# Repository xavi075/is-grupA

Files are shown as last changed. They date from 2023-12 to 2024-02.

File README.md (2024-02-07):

# Sensor Center: control and automate crop irrigation

## General description
Over the past few months, Ferran, Arnau, and I have been collaborating on a project to control and automate crop irrigation. The device is autonomous and includes a battery that is recharged with solar energy. 

The project involves designing and 3D printing the encapsulation, developing the device firmware, creating software for a master device that connects the sensors to a cloud database through an API, and designing an intuitive graphical interface that is easy to use and fully portable for any electronic device. This allows the user to control their irrigation system from anywhere. 

The firmware was developed using C++, while the master software and database API were implemented in Python. MySQL was used as the database management system. The web application was developed with React and Typescript and its service was launched into production using Docker on a server.

> [!IMPORTANT]
> Some parts of the firmware are adapted to our hardware needings.

## Web Board
Web-board directory includes the application web project. It is responsive and has been designed based on the requirements of our university project.

> [!WARNING]
> All the packages that must be installed are registered in the package log and must be installed using `npm install` command

In order to run the web app locally, just use `npm start`. Also, currently the requests are pointing to the database. In case of running the database locally, it is strictly necessary to change the Endpoint in the `api.ts` file.

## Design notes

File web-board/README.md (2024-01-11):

# Sensor Center
> [!TIP]
> This is a tip

In order to run this web server, NodeJs and Npm are needed for the building.

Install NodeJs with the following command:

Install Npm with the following command:

Also it is needed to download all the required packages by React:

`npm install`

The last step is building the React project. For a local run:

`npm start`

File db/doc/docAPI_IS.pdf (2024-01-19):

# Documentació API Grup A

### Ferran Casanovas i Arnau Parcerisa

### 18 de gener de 2024

## Índex

1 Introducció | 1
2 Formats de les peticions | 2
3 Peticions POST | 2
4 Peticions GET | 10

## 1 Introducció

En aquest document s’hi pot trobar tota la documentació de la API creada pel grup A, format per l’Arnau Parcerisa, el Xavier Massana i el Ferran Casanovas.

1

EPSEM - Sistemes TIC - 2023/24 | Integració de Sistemes

Aquesta API permet, mitjançant mètodes GET i POST, consultar i inserir dades a la base de dades MySQL dissenyada. Per a la programació d’aquesta API s’ha utilitzat Python3 i Flask.

## 2 Formats de les peticions

En cadascuna de les peticions, s’especifica com ha de ser el format i quines dades contindrà la resposta. En cas de que la petició sigui correcta i no hi hagin errors durant l’execució, el codi de resposta serà 200 i el seu format serà diferent en cada petició, donat que en cadascuna es voldran obtenir dades diferents. No obstant, sempre s’indicarà que no hi han hagut errors retornant una petició amb el format següent:

{
{
"success" = True,
}

En cas que la petició sigui incorrecta, ja sigui perquè aquesta és sintàcticament incorrecta, perquè no s’especifiquen les dades necessàries o perquè el client no està autoritzat per accedir i/o modificar el recurs, el codi de resposta serà 400. Si es produeix algun error durant l’execució el codi de resposta serà 500. En ambdos casos, el format de la resposta serà el següent:

{
"success" = False,
"error" = "descripció del error" }

## 3 Peticions POST

A continuació es descriuen les funcionalitats de totes les peticions de la API que utilitzen el mètode POST, incloent una breu descripció, característiques de seguretat (si n’hi han), el format de la petició i el format de la resposta per a cada petició. Cal destacar que en tots els casos s’espera que en el cos de la petició s’hi inclogui un objecte json.

### 3.1 /assignaDispositiuUsuari

Endpoint de Flask per assignar un dispositiu a un usuari. Només permet assignar-lo si el dispositiu està desassignat, és a dir, que no està assignat a cap altra usuari.

2

### 3.1.1 Format de la petició

{
"idDispositiu": (int),
"idUsuari": (int),
"nomDispositiu": (str)
}

En aquest cas, es poden ocultar camps del json. Els camps del json idDispositiu, idUsuari i nomDispositiu son OBLIGATORIS.

### 3.1.2 Format de la resposta

{
"success" = True
"dades":
{
"idHardcode": (str)
}
}

### 3.2 /desassignaDispositiu

Endpoint de Flask per desassignar un dispositiu a un usuari. Només es pot desassignar un dispositiu si aquest està assignat a un usuari. A més, s’esborren totes les dades del dispositiu de les taules de dades corresponents a les dades de humitat i temperatura (dadesDispositius) i a la de canvis d’estat de reg (canvisReg).

### 3.2.1 Format de la petició

{
"idDispositiu": (int),
"idUsuari": (int)
}

Els camps de la petició idDispositiu i idUsuari són obligatoris.

### 3.2.2 Format de la resposta

{
"success" = True
}

### 3.3 /inserirDada

Endpoint de Flask per inserir dades a la taula dadesDispositius.

3

### 3.3.1 Format de la petició

{
"idHardcode": (str),
"dadaHum": (decimal),
"dadaTemp": (decimal),
}

En aquest cas, es poden ocultar camps del del json. No es pot inserir dades sense que no estigui assignat a cap usuari. Tots els camps del json són OBLIGATORIS.

### 3.3.2 Format de la resposta

{
"success" = True
}

### 3.4 /inserirDispositiu

Endpoint de Flask per inserir dades a la taula dispositius. Permet inserir un dispositiu no assignat a cap usuari. El fet d’inserir un dispositiu no assignat es fa per tal de facilitar la feina del front-end per assignar un nou dispositiu a un usuari. Tot i així, si que és obligatori afegir-li un id que el permeti identificar amb el hardware, anomenat idHardcode.

### 3.4.1 Format de la petició

{
"idHardcode": (str),
"idUsuariPropietari": (int) / None, "nomDispositiu": (str) / None "llindarMinimReg": (decimal) / None, "llindarMaximReg": (decimal) / None }

En aquest cas, es poden ocultar camps del del json. Si es vol inserir un dispositiu que no estigui assignat a cap usuari, s’ha enviar un json que només contingui el id del hardware. Tots els camps del json són OPCIONALS en excepció del idHardcode que és OBLIGATORI.

### 3.4.2 Format de la resposta

Quan el dispositiu s’insereix correctament, s’especifica el id que se li ha assignat al dispositiu inserit.

4

{
"success": True,
"idDispositiu": (int),
"idHardcode": (str)
}

### 3.5 /inserirEstatReg

Endpoint de Flask per inserir dades a la taula canvisReg. Aquest només insereix és els canvis, és a dir només insereix la dada si l’últim estat del reg del dispositiu és diferent.

### 3.5.1 Format de la petició

{
"idHardcode": (int),
"estatReg": (bool)
}

Si el cos de la petició no conté un json amb els camps idHardcode i estatReg, les dades no s’inseriran. Tots els camps del json són OBLIGATORIS.

### 3.5.2 Format de la resposta

Si tot funciona correctament, s’especifica si la dada s’ha inserit o no depenent de si aquesta és diferent o no a l’últim estat del reg del dispositiu guardat.

{
"success" = True,
"dadaInserida": (bool)
}

### 3.6 /inserirUsuari

Endpoint de Flask per inserir dades a la taula usuaris. Al inserir un usuari, s’insereix a la base de dades la data utf de creació de l’usuari, aquesta data no s’ha d’especificar en la petició.

### 3.6.1 Seguretat

S’ha d’enviar la contrasenya sense aplicar cap funció de hash, ja que la mateixa petició és la que s’encarrega d’aplicar-lo.

5

### 3.6.2 Format de la petició

{
"email": (str),
"nomUsuari": (str),
"contrasenya": (str)
}

Si el cos de la petició no conté un json amb els camps email, nomUsuari i contrasenya, les dades de l’usuari no s’inseriran. Tots els camps del json són OBLIGATO-RIS.

### 3.6.3 Format de la resposta

Quan l’usuari s’insereix correctament, s’especifica el id que se li ha assignat a l’usuari insertat.

{
"success": True,
"idUsuariInsertat": (int)
}

### 3.7 /modificaContrasenya

Endpoint de Flask per modificar la contrasenya d’un usuari. Per tal de modificarla és necessari indicar la contrasenya actual i que aquesta sigui correcta.

### 3.7.1 Seguretat

S’ha d’enviar tant la contrasenya actual com la nova contrasenya sense aplicar cap funció de hash, donat que la mateixa petició s’encarrega de:

- Aplicar la funció de hash a la contrasenya actual indicada i comprovar que coincideixi amb la guardada a la base de dades.
- Guardar la nova contrasenya amb la funció de hash aplicada.

### 3.7.2 Format de la petició

{
"idUsuari": (int),
"contrasenya": (str),
"novaContrasenya": (str)
}

Si el cos de la petició no conté un json amb els camps idUsuari, contrasenya i novaContrasenya, la contrasenya no es modificarà. Tots els camps del json són OBLIGATORIS.

6

### 3.7.3 Format de la resposta

Indica si s’ha modificat la contrasenya correctament.

{
"success" = True
}

### 3.8 /modificaLlindars

Endpoint de Flask per modificar els llindars de reg d’un dispositiu. S’emmagatzemen els llindars modificats per si es demana en la petició GET /obtenirModificacionsLlindars. Si ja hi ha algun canvi de llindar entrat, se’l substitueix.

### 3.8.1 Format de la petició

{
"idDispositiu": (int),
"llindarMinimReg": (decimal), "llindarMaximReg": (decimal) }

Si el cos de la petició no conté un json amb els camps idDispositiu, llindarMinimReg i llindarMaximReg, la petició donarà a un error amb codi 400. Els camps del json idDispositiu, llindarMinimReg i llindarMaximReg són OBLIGATORIS.

### 3.8.2 Format de la resposta

Indica si s’han modificat els llindars correctament.

{
"success" = True
}

### 3.9 /verificaLogIn

Endpoint de Flask per obtenir si les credencials de log in es corresponen a les credencials de la base de dades. Si troba les credencials, retorna el identificador de l’usuari per facilitar el logIn.

### 3.9.1 Seguretat

S’ha d’enviar la contrasenya sense aplicar cap funció de hash, ja que la mateixa petició s’encarrega d’aplicar-la i comprovar que coincideixi amb la guardada a la base de dades.

7

### 3.9.2 Format de la petició

{
"emailUsuari": (str),
"contrasenya": (str)
}

Si el cos de la petició no conté un json amb els camps emailUsuari i contrasenya, la petició donarà a un error amb codi 400. Tots els camps del json són OBLI-GATORIS.

### 3.9.3 Format de la resposta

Indica si s’ha trobat una coincidència de les credencials a la base de dades o no i retorna l’identificador de l’usuari per facilitar el LogIn. També retorna si l’usuari està verificat o no.

{
"success" = True,
"credencialsTrobades": (bool), "idUsuari": (int) / None,
"usuariVerificat": (bool)
}

### 3.10 /verificaUsuari

Endpoint de Flask per verificar el codi de verificació d’un usuari.

### 3.10.1 Format de la petició

{
"idUsuari": (int),
"codi": (str)
}

Si el cos de la petició no conté un json amb els camps idUsuari i codi, la petició donarà a un error amb codi 400. Tots els camps del json són OBLIGATORIS.

### 3.10.2 Format de la resposta

Indica si s’ha trobat una coincidència del codi de verificació a la base de dades o no i un boolea que indica si el codi introduit i el de la base de dades eren els mateixos i, per tant, l’usuari s’ha verificat (True) o, en cas contrari, els codis no coincideixen i, per tant, l’usuari no s’ha verificat (False).

8

{
"success" = True,
"usuariVerificat": (bool)
}

9

## 4 Peticions GET

A continuació es decriuen les funcionalitats de totes les peticions de la API que utilitzen el mètode GET, incloent una breu descripció, descripció dels paràmetres de la petició, el format de la resposta i exemples per a cada petició. Cal destacar que el format de resposta de totes les peticions GET serà el següent:

{
"success" = True,
"dades":
[
]
}

On dintre de la llista dades s’hi emmagatzemaran les dades que es volen consultar, generalment dintre de diccionaris on cada diccionari es correspon a una fila de la base de dades. Les dades que es retornaran en cada petició i el seu format s’especificarà en la descripció de cadascuna d’elles.

### 4.1 /obtenirCanvisReg

Endpoint de Flask per obtenir dades de la taula canvisReg, on estan emmagatzemats els canvis en l’estat del reg.

### 4.1.1 Paràmetres de la petició

- idUsuari (opcional): identificador del usuari del qual es vol obtenir els canvis en l’estat del reg dels seus dispositius assignats.
- idDispositiu (opcional): identificador del dispositiu del qual es volen obtenir els canvis en l’estat del reg.
- dataInici (opcional): data a partir de la qual es volen obtenir els canvis en l’estat del reg.
- dataFi (opcional): data fins a la qual es volen obtenir els canvis en l’estat del reg.

Si no s’especifiquen cap dels paràmetres, s’obtindran totes les dades emmagatzemades en la taula canvisReg. Si s’especifiquen els paràmetres idUsuari i idDispositiu, es filtrarà per l’identificador del dispositiu. Els paràmetres dataInici i/o dataFi han d’anar acompanyats del paràmetre idUsuari o idDispositiu, en cas contrari s’obtindran totes les dades sense filtrar per data. Es pot especificar el paràmetre dataInici sense especificar dataFi, però si s’especifica dataFi sense especificar dataInici aquest s’ignorarà.

10

### 4.1.2 Format de la resposta

{
"success" = True,
"dades":
[
{
"idDispositiu": (int),
"dataHora": (datetime),
"estatReg": (bool)
},
]
}

### 4.1.3 Exemples de peticions

- Obtenir totes les dades:

GET /obtenirCanvisReg

- Obtenir totes les dades dels dispositius assignats a un usuari en concret:

GET /obtenirCanvisReg?idUsuari=1

- Obtenir totes les dades d’un dispositiu:

GET /obtenirCanvisReg?idDispositiu=1

- Obtenir totes les dades dels dispositius assignats a un usuari indicant data
inici i data fi:

GET /obtenirCanvisReg?idUsuari=1&dataInici=2023-11-16 00:01:00 &dataFi=31-12-2023 23:59:00

- Obtenir totes les dades d’un dispositiu indicant data inici i data fi:

GET /obtenirCanvisReg?idDispositiu=1&dataInici=01-01-2023 00:01:00 &dataFi=31-12-2023 23:59:00

### 4.2 /obtenirDadesDispositius

Endpoint de Flask per obtenir dades de la taula dadesDispositius, on estan emmagatzemats els valors de temperatura i d’humitat.

### 4.2.1 Paràmetres de la petició

- idUsuari (opcional): identificador del usuari del qual es volen obtenir les dades dels seus dispositius assignats.

11

- idDispositiu (opcional): identificador del dispositiu del qual es volen obtenir les dades.
- dataInici (opcional): data a partir de la qual es volen obtenir les dades.
- dataFi (opcional): data fins a la qual es volen obtenir les dades.

Si no s’especifiquen cap dels paràmetres, s’obtindran totes les dades emmagatzemades en la taula dadesDispositius. Si s’especifiquen els paràmetres idUsuari i idDispositiu, es filtrarà per l’identificador del dispositiu. Els paràmetres dataInici i/o dataFi han d’anar acompanyats del paràmetre idUsuari o idDispositiu, en cas contrari s’obtindran totes les dades sense filtrar per data. Es pot especificar el paràmetre dataInici sense especificar dataFi, però si s’especifica dataFi sense especificar dataInici aquest s’ignorarà.

### 4.2.2 Format de la resposta

{
"success" = True,
"dades":
[
{
"idDispositiu": (int),
"dataHora": (datetime),
dadaHum: (decimal),
dataTemp: (decimal
},
]
}

### 4.2.3 Exemples de peticions

- Obtenir totes les dades:

GET /obtenirDadesDispositius

- Obtenir totes les dades dels dispositius assignats a un usuari en concret:

GET /obtenirDadesDispositius?idUsuari=1

- Obtenir totes les dades d’un dispositiu:

GET /obtenirDadesDispositius?idDispositiu=1

- Obtenir totes les dades dels dispositius assignats a un usuari indicant data inici i data fi:

GET /obtenirDadesDispositius?idUsuari=1&dataInici=2023-11-16 00:01:00 &dataFi=31-12-2023 23:59:00

12

- Obtenir totes les dades d’un dispositiu indicant data inici i data fi:

GET /obtenirDadesDispositius?idDispositiu=1&dataInici=01-01-2023 00:01:00 &dataFi=31-12-2023 23:59:00

### 4.3 /obtenirDispositius

Endpoint de Flask per obtenir dades de la taula dispositius.

### 4.3.1 Paràmetres de la petició

- idUsuari (opcional): id de l’usuari del qual es volen obtenir les dades dels seus dispositius assignats.
- nomDispositiu (opcional): nom del dispositiu del qual es volen obtenir les dades. Sempre ha d’anar acompanyat d’un idUsuari, ja que diferents usuaris poden tenir dispositius amb el mateix nom.
- idDispositiu (opcional): id del dispositiu del qual es poden obtenir les dades.

Si no s’especifica cap dels paràmetres, s’obtindran les dades de tots els dispositius. Si s’especifica el paràmetre idDispositiu, es filtrarà per aquest encara que s’especifiquin més paràmetres.

### 4.3.2 Format de la resposta

{
"success" = True,
"dades":
[
{
"id": (int),
"idHardcode": (str),
"idUsuariPropietari": (int), "nomDispositiu": (str),
"llindarMinimReg": (decimal), "llindarMaximReg": (decimal) },
]
}

### 4.3.3 Exemples de peticions

- Obtenir totes les dades:

GET /obtenirDispositius

13

- Obtenir les dades dels dispositius d’un usuari a partir d’un idUsuari:

GET /obtenirDispositius?idUsuari=1

- Obtenir les dades d’un dispositiu en concret a partid del id:

GET /obtenirDispositius?idDispositiu=1

- Obtenir les dades d’un dispositiu en concret a partir del id del usuari i el nom de dispositiu:

GET /obtenirDispositius?idUsuari=1&nomDispositiu=dispo1

### 4.4 /obtenirDispositiusDesassignats

Endpoint de Flask per obtenir els dispositius que no estan assignats a cap usuari, és a dir, que la columna idUsuariPropietari = NULL.

### 4.4.1 Paràmetres de la petició

Aquesta petició no té paràmetres, donat que al realitzar-la s’obtindran tots els dispositius desassignats.

### 4.4.2 Format de la resposta

{
"success" = True,
"dades":
[
{
"idDispositiu": (int),
"idHardcode": (str)
},
]
}

### 4.4.3 Exemples de peticions

- Obtenir tots els dispositius desassignats:

GET /obtenirDispositiusDesassignats

### 4.5 /comprovacioDispositiuInserit

Endpoint de Flask per comprovar si un dispositiu ha sigut inserit a la base de dades i està assignat.

14

### 4.5.1 Paràmetres de la petició

- idHardcode (obligatori): identificador únic del dispositiu.

Si no s’especifica el paràmetre idHardcode, la petició donarà lloc a un error amb codi 400. El paràmetre de la petició és OBLIGATORI.

### 4.5.2 Format de la resposta

{
"success": True,
"dispositiuTrobat": (bool), "assignat": (bool)
}

### 4.5.3 Exemples de peticions

- Comprovar si un dispositiu està inserit a la base de dades:

GET /comprovacioDispositiuInserit?idHardcode=A

### 4.6 /obtenirUsuaris

Endpoint de Flask per obtenir dades de la taula usuaris. Permet obtenir les dades d’un usuari en concret o de tots els usuaris. Cal tenir en compte que mitjançant aquest mètode mai es podran obtenir les contrasenyes dels usuaris, ni tan sols amb la funció hash aplicada.

### 4.6.1 Paràmetres de la petició

- idUsuari (opcional): identificador del usuari del qual es volen obtenir les dades.
- emailUsuari (opcional): correu electrònic del usuari del qual es volen obtenir les dades.

Si no s’especifica cap dels dos paràmetres, s’obtindran les dades de tots els usuaris. Si s’especifiquen els dos paràmetres, es filtrarà per l’identificador de l’usuari.

### 4.6.2 Format de la resposta

{
"success" = True,
"dades":
[
{
"id": (int),

15

"email": (str),
nomUsuari: (str),
dataCreacioUsuari: (datetime) },
]
}

### 4.6.3 Exemples de peticions

- Obtenir les dades de tots els usuaris:

GET /obtenirUsuaris

- Obtenir les dades d’un usuari en concret mitjançant el id:

GET /obtenirUsuaris?idUsuari=1

- Obtenir les dades d’un usuari en concret mitjançant el email:

GET /obtenirUsuaris?emailUsuari=usuari@exemple.com

### 4.7 /obtenirUltimReg

Endpoint de Flask per obtenir les dades del últim reg d’un dispositiu.

### 4.7.1 Paràmetres de la petició

- idDispositiu (obligatori): identificador del dispositiu del qual es volen obtenir les dades de l’últim reg.

Si no s’especifica el paràmetre idDispositiu, la petició donarà lloc a un error amb codi 400. El paràmetre de la petició és OBLIGATORI.

### 4.7.2 Format de la resposta

{
"success" = True,
"dades":
[
{
"dataHoraInici": (datetime) / "", "dataHoraFi": (datetime) / ""
}
]
}

Es poden donar tres opcions, que donen tres respostes diferents:

16

- S’ha començat i s’ha acabat de regar: l’últim reg s’ha finalitzat, pel que la bomba es troba parada. dataHoraInici indica el moment en el qual s’ha començat a regar i dataHoraFi indica el moment en el qual s’ha finalitzat el reg.
- S’ha començat a regar i no s’ha acabat el reg: l’últim reg no s’ha finalitzat, pel que la bomba es troba engegada. dataHoraInci indica el moment en el qual s’ha començat a regar i dataHoraFi és un string buit.
- No s’ha regat mai: no es tenen dades de cap reg del dispositiu. Tant dataHoraInici com dataHoraFi són strings buits.

### 4.7.3 Exemples de peticions

- Obtenir les dades de l’últim reg d’un dispositiu:

GET /obtenirUltimReg?idDispositiu=1

### 4.8 /obtenirUltimRegUsuari

Endpoint de Flask per obtenir les dades del últim reg de tots els dispositiu d’un usuari.

### 4.8.1 Paràmetres de la petició

- idUsuari (obligatori): identificador del usuari del qual es volen obtenir les dades de l’últim reg de tots els seus dispositius.

Si no s’especifica el paràmetre idUsuari, la petició donarà lloc a un error amb codi 400. El paràmetre de la petició és OBLIGATORI.

### 4.8.2 Format de la resposta

{
"dades":
[
{
"idDispositiu": (int) / "", "nomDispositiu": (str) / "", "dataHoraInici": (datetime) / "", "dataHoraFi": (datetime) / "" },
{
"idDispositiu": (int) / "", "nomDispositiu": (str) / "", "dataHoraInici": (datetime) / "", "dataHoraFi": (datetime) / ""

17

}
]
"success": True,
}

Es poden donar tres opcions, que donen tres respostes diferents:

- S’ha començat i s’ha acabat de regar: l’últim reg s’ha finalitzat, pel que la bomba associada al dispositiu es troba parada. dataHoraInici indica el moment en el qual s’ha començat a regar i dataHoraFi indica el moment en el qual s’ha finalitzat el reg. idDispositiu indica al dispositiu on està connectada la bomba i nomDispositiu indica el seu nom donat.
- S’ha començat a regar i no s’ha acabat el reg: l’últim reg no s’ha finalitzat, pel que la bomba es troba engegada. dataHoraInci indica el moment en el qual s’ha començat a regar i dataHoraFi és un string buit. idDispositiu indica al dispositiu on està connectada la bomba i nomDispositiu indica el seu nom donat.
- No s’ha regat mai: no es tenen dades de cap reg de cap dispositiu de l’usuari. Tant dataHoraInici com dataHoraFi com idDispositiu com nomDispositiu són strings buits.

### 4.8.3 Exemples de peticions

- Obtenir les dades de l’últim reg dels dispositius d’un usuari:

GET /obtenirUltimRegUsuari?idUsuari=1

### 4.9 /obtenirUltimaDadaDispositiu

Endpoint de Flask per obtenir les últimes dades de la taula dadesDispositius. Això inclou obtenir les últimes dades d’un dispositiu en concret o obtenir totes les dades dels dispositius assignats a un usuari.

### 4.9.1 Paràmetres de la petició

- idUsuari (opcional): identificador del usuari del qual es vol obtenir la última dada de cadascun dels dispositius que té assignats.
- idDispositiu (opcional): identificador del dispositiu del qual es vol obtenir la última dada.

Si no s’especifica ni el paràmetre idUsuari ni idDispositiu, la petició donarà lloc a un error amb codi 400. Si s’especifica el paràmetre idDispositiu, es filtrarà per aquest encara que s’especifiqui el paràmetre idUsuari. Els paràmetres de la petició són OPCIONALS, però és OBLIGATORI especificar-ne almenys un.

18

### 4.9.2 Format de la resposta

{
"success" = True,
"dades":
[
{
"idDispositiu": (int),
"nomDispositiu": (str),
"dataHora": (datetime),
"dadaHum": (decimal),
"dadaTemp": (decimal)
},
]
}

### 4.9.3 Exemples de peticions

- Obtenir la última dada d’un dispositiu:

GET /obtenirUltimaDadaDispositiu?idDispositiu=1

- Obtenir la última dada de tots els dispositius assignats a un usuari:

GET /obtenirUltimaDadaDispositiu?idUsuari=1

### 4.10 /obtenirModificacionsLlindars

Endpoint de flask per obtenir la última modificació en els llindars de reg de dispositius. Si es demana d’un dispositiu en concret, com que ja s’ha comunicat el canvi en el llindar, es borra de la llista.

### 4.10.1 Paràmetres de la petició

- idHardcode (opcional): identificador únic del dispositiu del qual es vol obtenir la última modificació en els llindars de reg..

Si no s’especifica el paràmetre, s’obtindran totes les últimes modificacions de llindars de qualsevol dispositiu.

### 4.10.2 Format de la resposta

{
"success" = True,
"dades":
[
{

19

"idHardcode": (str),
"llindarMinimReg": (decimal), "llindarMaximReg": (decimal) },
]
}

Si es retorna una llista buida, vol dir que no existeix cap modificació dels llindars per als paràmetres especificats.

### 4.10.3 Exemples de peticions

- Obtenir les últimes modificacions de llindars de tots els dispositius:

GET /obtenirModificacionsLlindars

- Obtenir la última modificació de llindars d’un dispositiu en concret:

GET /obtenirModificacionsLlindars?idHardcode=A

20

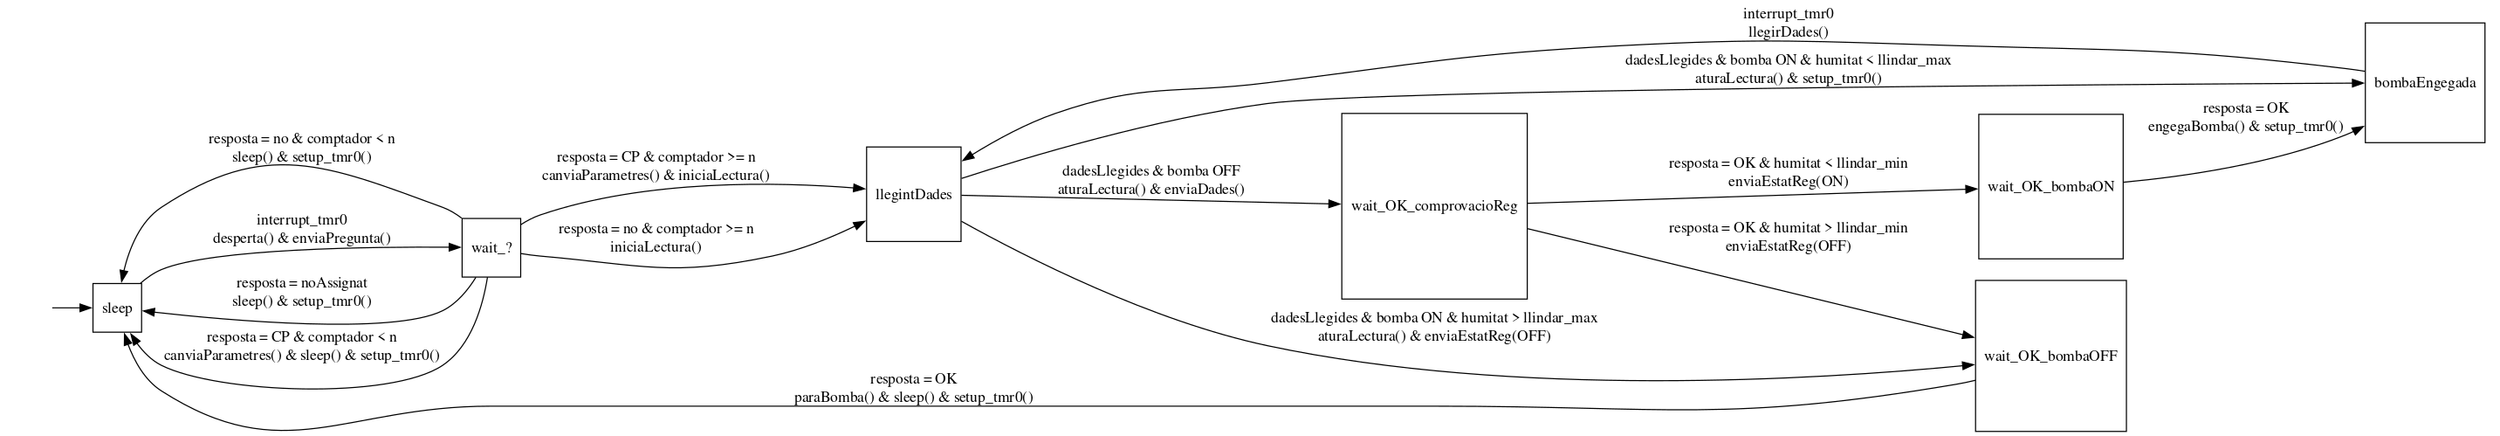
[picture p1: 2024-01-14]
slave/fsm_slave.png

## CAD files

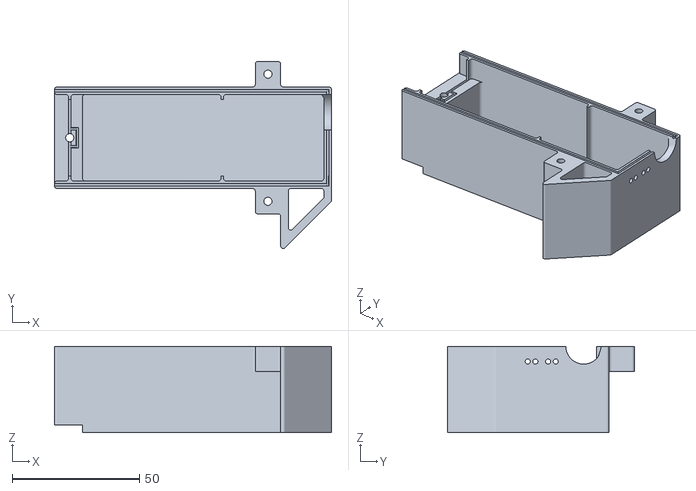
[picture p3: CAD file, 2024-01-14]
arxius3d/encapsulatInf-grupA.stl
109.0 x 73.6 x 34.0

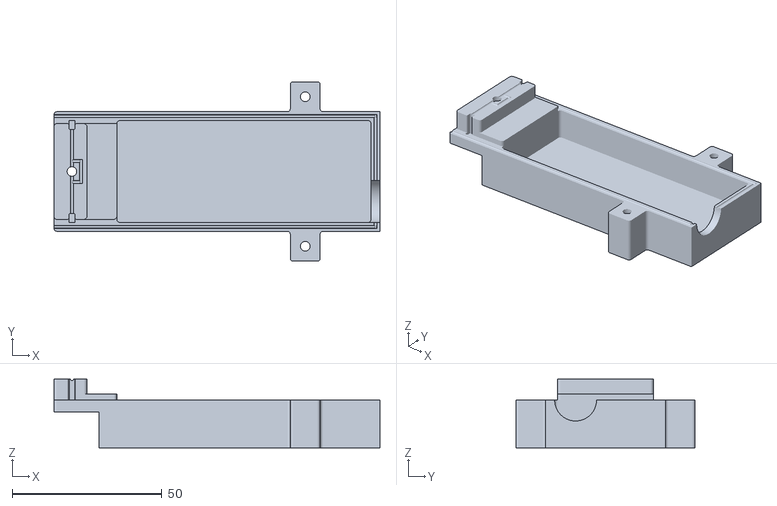
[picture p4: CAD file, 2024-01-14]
arxius3d/encapsulatTapa-grupA.stl
109.0 x 60.0 x 23.0

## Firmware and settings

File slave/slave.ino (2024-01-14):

#include <SPI.h>
#include <LoRa.h>
#include <avr/sleep.h>
#include <avr/power.h>

// per llegir el valor de la temperatura
#include <OneWire.h>
#include <DallasTemperature.h>

#include "adc.h"
#include "modulator.h"
#include "secure.h"
#include "tmr0.h"
#include "tmr2.h"

// Definició dels estats que pot tenir el slave
enum estats_slave {
  sleep,
  wait_resp,
  llegintDades,
  wait_OK_comprovacioReg,
  wait_OK_bombaON,
  wait_OK_bombaOFF,
  bombaEngegada
};
volatile estats_slave estat;

uint8_t localAddress[4] = {0xAA, 0x00, 0x00, 0x00}; // adreça del dispositiu
uint8_t masterAddress[4] = {0x00, 0x00, 0x00, 0x00}; // adreça del dispositiu master
int interval_s = 6000; // interval de temps entre comunicacions amb master

const int num_comunicacions_llegirDades = 6; // variable per indicar cada quantes comunicacions amb el master es llegeixen dades
int num_comunicacions_llegirDades_restants = num_comunicacions_llegirDades - 1; // comunicacions restants per a llegir dades

volatile uint8_t msgId = 0; // comptador dels missatges de sortida
volatile uint8_t lastMsgId; // variable per emmagatzemar l'últim identificador de missatge enviat
String lastOutgoing; // variable per emmagatzemar l'últim missatge
volatile bool lastMsgRespos_flag = true; // flag per indicar si l'últim missatge enviat s'ha respos
const int intervalRepeticioMsg_s = 10; // interval de temps per repetir missatges 
volatile int num_msgRep; // comptador dels cops que s'ha repetit l'últim missatge

// flag per indicar que s'està comunicant amb el master i que no s'ha d'entrar en mode sleep
volatile bool comunicacioMasterFlag = false; 

volatile float llindarMinReg; // llindar a partir del qual es comença a regar
volatile float llindarMaxReg; // llindar a partir del qual es para de regar

const int num_mostresHumitat = 100; // nombre total de mostres d'humitat que es llegiran per cada lectura
volatile int num_mostresHumitat_restants = num_mostresHumitat - 1; // per emmagatzemar el nombre de mostres d'humitat que queden per acabar la lectura
volatile int contenidor_valorHumitat; // variable en la qual es sumaran totes les mostres d'humitat per a després realitzar la mitjana
volatile bool dadesLlegidesFlag; // flag per indicar que s'han llegit totes les mostres d'humitat
float valorHumitat; // variable per emmagatzemar el valor d'humitat llegit

const int valorMaximHumitat = 223; // valor d'humitat amb sensor totalment sec (referència 0% d'humitat)
const int valorMinimHumitat = 45; // valor d'humitat amb sensor totalment mullat (referència 100% d'humitat)

const int pin_temperatura = 14; // pin per on es llegeix la temperatura
OneWire oneWire(pin_temperatura);
DallasTemperature sensors(&oneWire);
float valorTemperatura; // variable per emmagatzemar el valor de temperatura llegit

const int interval_LecturaDades_bombaON_s = 10; // interval de temps per llegir la humitat novament per comprovar si s'ha regat suficient

const int pin_bomba = 6; // pin per activar i desactivar la bomba

// canvia l'estat i el printa
void canviaEstat(estats_slave nouEstat) {
  estat = nouEstat;
  printaEstat();
}

// printa l'estat actual. Únicament serveix per debugar
void printaEstat() {
  switch (estat) {
    case sleep:
      Serial.println("Estat sleep");
      break;
    case wait_resp:
      Serial.println("Estat wait_resp");
      break;
    case llegintDades:
      Serial.println("Estat llegintDades");
      break;
    case wait_OK_comprovacioReg:
      Serial.println("Estat wait_OK_comprovacioReg");
      break;
    case wait_OK_bombaON:
      Serial.println("Estat wait_OK_bombaON");
      break;
    case wait_OK_bombaOFF:
      Serial.println("Estat wait_OK_bombaOFF");
      break;
    case bombaEngegada:
      Serial.println("Estat bombaEngegada");
      break;
    default:
      Serial.println("Estat no reconegut");
      break;
  }
}

// per iniciar la comunicació amb el master. Surt de l'estat sleep i activa el flag
// de comunicació amb el master
void iniciaComunicacioMaster() {
  comunicacioMasterFlag = true;
  canviaEstat(wait_resp);

  sendMessage("preg");

  LoRa.receive();
}

// per finalitzar la comunicació amb el master. Posa el dispositiu amb mode sleep
// i reinicia el timer 0 per tal de que torni a començar la comunicació.
// Canvia al estat sleep i desactiva el flag de comunicació amb el master
void acabaComunicacioMaster() {
  if (num_comunicacions_llegirDades_restants > 0) num_comunicacions_llegirDades_restants--;

  paraBomba();
  comunicacioMasterFlag = false;
  canviaEstat(sleep);
  setup_tmr0(interval_s, iniciaComunicacioMaster);

}

// modifica els llindars de reg del dispositiu
void canviaLlindars(float llindarMin, float llindarMax) {
  Serial.println("Canviant llindars");
  
  llindarMinReg = llindarMin;
  llindarMaxReg = llindarMax;

  
  Serial.print("llindarMin: ");
  Serial.println(llindarMinReg);
  Serial.print("llindarMax: ");
  Serial.println(llindarMaxReg);
}

// s'executa en la interrupció del timer 0 per tornar a calcular el valor de l'humitat després de regar un cert temps.
// Inicia la lectura de dades i modifica l'estat a llegintDades
void bombaEngegada_to_llegintDades() {
  iniciaLectura();
  canviaEstat(llegintDades);
}

// inicia la lectura de dades d'humitat. Això implica engegar el modulator i les interrupcions del timer 2
void iniciaLectura() {
  modulator_set(true);
  tmr2_set(64);
  start_ADC();

  dadesLlegidesFlag = false;
  contenidor_valorHumitat = 0;
  num_mostresHumitat_restants = num_mostresHumitat - 1;
}

// atura la lectura de dades d'humitat. Això implica aturar el modulator i les interrupcions del timer 2
void aturaLectura () {
  modulator_set(false);
  tmr2_set(0);
}

// envia les dades d'humitat i de temperatura especificades en el format que espera el master ("d-H:100T:40")
void enviaDades() {
  String humitat_string = String(valorHumitat);
  String temperatura_string = String(valorTemperatura);

  sendMessage("d-H:" + humitat_string + "T:" + temperatura_string);
}

// envia l'estat del reg
void enviaEstatReg(String estatReg) {
  sendMessage("r-" + estatReg);
}

// engega la bomba
void engegaBomba() {
  digitalWrite(pin_bomba, HIGH);
}

// para la bomba
void paraBomba() {
  digitalWrite(pin_bomba, LOW);
}

// consulta l'estat de la bomba. True si està engegada i False si està parada
bool comprovaReg() {
  return (digitalRead(pin_bomba) == 1);
}

void setup() {
  Serial.begin(9600);
  while (!Serial);

  Serial.println("LoRa Slave");

  delay(5000);

  LoRa.setPins(10,5,2); //Per sensor
  while(!LoRa.begin(866E6));
  Serial.println("Starting LoRa!");

  delay(200);

  // iniciem el el timer0 per a la comunicació amb el master 
  setup_tmr0(interval_s, iniciaComunicacioMaster);

  // iniciem el modulator, el timer2 inicialment parat i l'ADC (utilitzats en la lectura de dades d'humitat)
  modulator_init();
  setup_tmr2(124, 0);
  setup_ADC(1,5,16);

  // per llegir la temperatura
  sensors.begin();

  //register the receive callback
  LoRa.onReceive(onReceive);
  //put the radio into receive mode
  LoRa.receive();

  // configurem el mode de baix consum
  set_sleep_mode(SLEEP_MODE_IDLE);
  sleep_enable();

  // iniciem l'estat del slave a sleep
  estat = sleep;

  // inicialitzem els valors per defecte dels llindars de reg
  llindarMinReg = 50;
  llindarMaxReg = 75;

  // inicialitzem el pin de la bomba com a sortida i activem el pin ENA (PC3 = A3/17)
  pinMode(pin_bomba, OUTPUT);
  pinMode(17, OUTPUT);
  digitalWrite(17, HIGH);

}

void loop() {
  if (!comunicacioMasterFlag) {
    sleep_mode();
  }

  if (estat == llegintDades) {
    if (dadesLlegidesFlag) { // s'han acabat de llegir les dades
      // en tots els casos aturem la lectura de dades
      aturaLectura();

      // càlcul del valor mitjà d'humitat
      float avg_humitat = contenidor_valorHumitat / num_mostresHumitat;

      // càlcul per obtenir l'humitat en percentatge
      valorHumitat = ((valorMaximHumitat - avg_humitat)/(valorMaximHumitat - valorMinimHumitat))*100;
      if (valorHumitat < 0) valorHumitat = 0;
      else if (valorHumitat > 100) valorHumitat = 100;
      Serial.println(valorHumitat);

      // obtenim la temperatura
      sensors.requestTemperatures();  // Solicitar la temperatura al sensor
      valorTemperatura = sensors.getTempCByIndex(0);  // Obtener la temperatura en grados Celsius
      Serial.println(valorTemperatura);

      if (!comprovaReg()) { // la bomba està OFF
        enviaDades(); // enviem els valors d'humitat llegits
        // modifiquem l'estat
        canviaEstat(wait_OK_comprovacioReg);
      }
      else { // la bomba està ON
        if (valorHumitat < llindarMaxReg) { // seguim amb la bomba ON i llegintDades
          setup_tmr0(interval_LecturaDades_bombaON_s, bombaEngegada_to_llegintDades);
          // modifiquem l'estat
          canviaEstat(bombaEngegada);
        }
        else { // iniciem procediment per parar la bomba
          enviaEstatReg("OFF");
          // modifiquem l'estat
          canviaEstat(wait_OK_bombaOFF);
        }
      }
      
    }
  }
}

// per enviar un missatge al master per LoRa
void sendMessage(String outgoing){
  Serial.print("Sending packet: ");
  Serial.println(msgId);

  // send packet
  LoRa.beginPacket();
  LoRa.write(masterAddress, 4);
  LoRa.write(localAddress, 4);
  LoRa.write(msgId);
  
  //uint8_t crc[4] = {0x00, 0x00, 0x00, 0x00}; // substituir per calcul de CRC
  uint8_t crc[4];
  calcularCRC(crc, outgoing.c_str(), outgoing.length());
  LoRa.write(crc, 4);

  LoRa.write(outgoing.length());

  // xifrem el paquet
  char outgoingXifrat[outgoing.length()];
  encrypt_xor(outgoing.c_str(), outgoingXifrat, 0xAA);
  
  //LoRa.print(outgoing);
  LoRa.print(outgoingXifrat);

  LoRa.endPacket();

  // guardem el missatge i el msgId enviat i marquem que no s'ha respòs
  lastOutgoing = outgoing;
  lastMsgId = msgId;
  lastMsgRespos_flag = false;

  // activem la repetició del missatge per si el master no respon
  num_msgRep = 0;
  setup_tmr0(intervalRepeticioMsg_s, repetirMissatge);

  if (msgId < 255) msgId++;
  else msgId = 0;

  LoRa.onReceive(onReceive);
  LoRa.receive();
}

// per tornar a enviar l'últim missatge enviat
void repetirMissatge() {
  // comprovem si s'ha respos a l'últim missatge
  if (lastMsgRespos_flag) return;

  // comprovem si el missatge s'ha repetit més de 5 cops, en aquest cas tanquem la comunicació amb el master
  num_msgRep++;
  if (num_msgRep >= 5) {
    acabaComunicacioMaster();
    return;
  }

  Serial.print("Repeating packet: ");
  Serial.println(lastMsgId);

  // send packet
  LoRa.beginPacket();
  LoRa.write(masterAddress, 4);
  LoRa.write(localAddress, 4);
  LoRa.write(lastMsgId);
  
  //uint8_t crc[4] = {0x00, 0x00, 0x00, 0x00}; // substituir per calcul de CRC
  uint8_t crc[4];
  calcularCRC(crc, lastOutgoing.c_str(), lastOutgoing.length());
  LoRa.write(crc, 4);

  LoRa.write(lastOutgoing.length());

  // xifrem el paquet
  char lastOutgoingXifrat[lastOutgoing.length()];
  encrypt_xor(lastOutgoing.c_str(), lastOutgoingXifrat, 0xAA);
  
  //LoRa.print(outgoing);
  LoRa.print(lastOutgoingXifrat);
 
  LoRa.endPacket();

  // activem la repetició del missatge per si el master continua sense respondre
  setup_tmr0(intervalRepeticioMsg_s, repetirMissatge);

  LoRa.onReceive(onReceive);
  LoRa.receive();
}

// Per llegir un missatge LoRa. S'executa quan es rep un missatge per LoRa
void onReceive(int packetSize){
  if (packetSize) {
    
    // read packet header bytes
    uint8_t recipient[4];
    LoRa.readBytes(recipient, 4);
    uint8_t senderAddress[4];
    LoRa.readBytes(senderAddress, 4);
    byte incomingMsgId = LoRa.read();
    uint8_t incomingCRC[4];
    LoRa.readBytes(incomingCRC, 4);
    byte incomingLength = LoRa.read();

    //comprovem si som el receptor del paquet
    if (memcmp(recipient, localAddress, 4) != 0) {
      Serial.println("Aquest missatge no és per mi.");
      return;
    }

    String incoming = "";
    // llegim el paquet rebut
    while (LoRa.available()) {
      incoming += (char)LoRa.read();
    }

    // desxifrem el paquet rebut
    char incomingDesxifrat_array[incoming.length()];
    decrypt_xor(incoming.c_str(), incomingDesxifrat_array, 0xAA);
    String incomingDesxifrat = String(incomingDesxifrat_array);

    // received a packet
    Serial.print("Received packet: ");
    //Serial.println(incoming);
    Serial.println(incomingDesxifrat);
    
    // verifiquem el CRC rebut i la longitud indicada
    if (!verificarCRC(incomingDesxifrat.c_str(), incomingLength, incomingCRC)) {
      Serial.print("CRC incorrecte: ");
      for (int i = 0; i < 4; i++)
        Serial.print(incomingCRC[i], HEX);
      return;
      Serial.println();
    }

    // comprovem si s'està responent a l'últim missatge enviat
    if (incomingMsgId == lastMsgId) { // resposta a l'últim missatge rebuda
      lastMsgRespos_flag = true;
      // aturem l'enviament del repetiment l'últim missatge
      stop_tmr0();
    }
    else {      
      Serial.println("El missatge no es correspon a l'últim missatge enviat");
      return;
    }

    // realizem una acció o una altra depenent de l'estat en el que ens trobem
    switch (estat) {
      case sleep:
        break;

      case wait_resp:
        Serial.println(num_comunicacions_llegirDades_restants);

        if (strcmp(incomingDesxifrat.c_str(), "NOASS") == 0)  {
          acabaComunicacioMaster();
        }
        else if (strcmp(incomingDesxifrat.c_str(), "NO") == 0)  {
          if (num_comunicacions_llegirDades_restants == 0) {
            num_comunicacions_llegirDades_restants = num_comunicacions_llegirDades - 1;
            iniciaLectura();
            canviaEstat(llegintDades);
          }
          else {
            acabaComunicacioMaster();
          }
        }
        else if (incomingDesxifrat.startsWith("CP-")) {
          // Obtenim el llidarMin i el llindarMax a modificar
          int posMin = incomingDesxifrat.indexOf("min:");
          int posMax = incomingDesxifrat.indexOf("max:");
          float llindarMin = incomingDesxifrat.substring(posMin + 4, posMax).toFloat();
          float llindarMax = incomingDesxifrat.substring(posMax + 4).toFloat();  

          canviaLlindars(llindarMin, llindarMax);
          
          if (num_comunicacions_llegirDades_restants == 0) {
            num_comunicacions_llegirDades_restants = num_comunicacions_llegirDades - 1;
            iniciaLectura();
            canviaEstat(llegintDades);
          }
          else {
            acabaComunicacioMaster();
          }
        }
        break;

      case wait_OK_comprovacioReg:

        if (strcmp(incomingDesxifrat.c_str(), "OK") == 0)  { // rebem la confirmació
          
          if (valorHumitat < llindarMinReg) {
            enviaEstatReg("ON");
            // modifiquem l'estat
            canviaEstat(wait_OK_bombaON);
          }

          else {
            enviaEstatReg("OFF");
            // modifiquem l'estat
            canviaEstat(wait_OK_bombaOFF);
          }
        }

      case wait_OK_bombaON:

        if (strcmp(incomingDesxifrat.c_str(), "OK") == 0)  { // rebem la confirmació
          engegaBomba();
          setup_tmr0(interval_LecturaDades_bombaON_s, bombaEngegada_to_llegintDades);
          // modifiquem l'estat
          canviaEstat(bombaEngegada);
        }

      case wait_OK_bombaOFF:

        if (strcmp(incomingDesxifrat.c_str(), "OK") == 0)  { // rebem la confirmació
          paraBomba();
          acabaComunicacioMaster();
        }

      default:
        Serial.println("Estat no reconegut");
        break;
    }
    

    LoRa.onReceive(onReceive);
    LoRa.receive();
  }
}

// interrupció del timer 2 que serveix per llegir les mostres d'humitat
ISR(TIMER2_COMPA_vect){
    uint8_t value=read8_ADC();
    start_ADC();
    num_mostresHumitat_restants --;
    contenidor_valorHumitat += value;
    if (num_mostresHumitat_restants == 0){ // ja s'han llegit totes les mostres que es volien
        dadesLlegidesFlag = 1;
    }
}  

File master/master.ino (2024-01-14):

#include <SPI.h>
#include <LoRa.h>

#include "secure.h"

uint8_t localAddress[4] = {0x00, 0x00, 0x00, 0x00}; // adreça del dispositiu master

// printa una adreça en hexadecimal pel port sèrie. Facilita la comunicació pel port sèrie
void printaAddress(uint8_t address[4]) {
  for (int i = 0; i < 4; i++) {
    // ens assegurem que sempre es printin dos dígits hexadeximals
    if (address[i] < 0x10) {
      Serial.print("0");
    }
    Serial.print(address[i], HEX);
  }
}

String llegeixPortSerie() {
  while (!Serial.available());
  
  String resposta;
  while (Serial.available() > 0) {
    // Lee el byte recibido
    char byteRecibido = Serial.read();

    resposta.concat(byteRecibido);
  }
  Serial.print("RESPOSTA = ");
  Serial.println(resposta);
  return resposta;
}

void setup() {
  Serial.begin(9600);
  while (!Serial);

  Serial.println("LoRa Master");

  while(!LoRa.begin(866E6));
  Serial.println("Starting LoRa!");

  //register the receive callback
  LoRa.onReceive(onReceive);
  //put the radio into receive mode
  LoRa.receive();
  
  pinMode(4,OUTPUT);
  digitalWrite(4,HIGH);
  delay(5000);
}

void loop() {
}

// per enviar un missatge a qualsevol esclau responent a un missatge per LoRa
void sendMessage(uint8_t destinationAddress[], byte msgIdResponse, String outgoing){
  // send packet
  LoRa.beginPacket();
  LoRa.write(destinationAddress, 4);
  LoRa.write(localAddress, 4);
  LoRa.write(msgIdResponse); //id del missatge que es respon

  //uint8_t crc[4] = {0x00, 0x00, 0x00, 0x00}; // substituir per calcul de CRC
  uint8_t crc[4];
  calcularCRC(crc, outgoing.c_str(), outgoing.length());
  LoRa.write(crc, 4);
  
  LoRa.write(outgoing.length());

  // xifrem el paquet
  char outgoingXifrat[outgoing.length()];
  encrypt_xor(outgoing.c_str(), outgoingXifrat, 0xAA);
  
  //LoRa.print(outgoing);
  LoRa.print(outgoingXifrat);
  
  LoRa.endPacket();
  
  Serial.print("Sending packet: ");
  Serial.println(outgoing);
}

// Per llegir un missatge LoRa. S'executa quan es rep un missatge per LoRa
void onReceive(int packetSize){
  if (packetSize) {
    
    // read packet header bytes
    uint8_t recipient[4];
    LoRa.readBytes(recipient, 4);
    uint8_t senderAddress[4];
    LoRa.readBytes(senderAddress, 4);
    byte incomingMsgId = LoRa.read();
    uint8_t incomingCRC[4];
    LoRa.readBytes(incomingCRC, 4);
    byte incomingLength = LoRa.read();

    //comprovem si som el receptor del paquet
    if (memcmp(recipient, localAddress, 4) != 0) {
      Serial.println("Aquest missatge no és per mi.");
      return;
    }

    String incoming = "";
    // llegim el paquet enviat
    while (LoRa.available()) {
      incoming += (char)LoRa.read();
    }

    // desxifrem el paquet rebut
    char incomingDesxifrat_array[incoming.length()];
    decrypt_xor(incoming.c_str(), incomingDesxifrat_array, 0xAA);
    String incomingDesxifrat = String(incomingDesxifrat_array);

    // received a packet
    Serial.print("Received packet: ");
    //Serial.println(incoming);
    Serial.println(incomingDesxifrat);
    
    // verifiquem el CRC rebut i la longitud indicada
    if (!verificarCRC(incomingDesxifrat.c_str(), incomingLength, incomingCRC)) {
      Serial.print("CRC incorrecte: ");
      for (int i = 0; i < 4; i++)
        Serial.print(incomingCRC[i], HEX);
      return;
    }

    // si el missatge és "preg" demanem si hi ha algun canvi de paràmetres
    if (strcmp(incomingDesxifrat.c_str(), "preg") == 0)  {
      // enviem missatge pel port sèrie
      Serial.print("?-");
      printaAddress(senderAddress);
      Serial.println();

      // llegim la resposta
      String resposta = llegeixPortSerie();
    
      // retornem la resposta al slave. La resposta pot ser "NO", "NOASS" o semblant a "CP-min:45.0max:70.6"
      sendMessage(senderAddress, incomingMsgId, resposta.c_str());
      Serial.print("Sending packet: ");
      Serial.println(resposta);
    }

    // si el missatge comença per "d-", significa que ens està enviant les dades d'humitat i temperatura
    else if (incomingDesxifrat.startsWith("d-"))  {
      // trobem la posició de "H:" i de "T:"
      int posH = incomingDesxifrat.indexOf("H:");
      int posT = incomingDesxifrat.indexOf("T:"); 
      
      // comprova si el format és l'esperat
      if (posH == -1 || posT == -1) return;

      // enviem missatge pel port sèrie
      Serial.print("d-");
      printaAddress(senderAddress);
      Serial.print("-");
      Serial.print(incomingDesxifrat.substring(posH));
      Serial.println();

      // llegim la resposta
      String resposta = llegeixPortSerie();
      
      // si ha anat bé, informem al slave enviant "OK"
      if (strcmp(resposta.c_str(), "OK") == 0) {
        sendMessage(senderAddress, incomingMsgId, resposta.c_str());
        Serial.print("Sending packet: ");
        Serial.println(resposta);
      }

    }

    // si el missatge comença per -r, signigica que està enviant l'estat del reg
    else if (incomingDesxifrat.startsWith("r-"))  {
      // obtenim la subcadena posterior a "r-""
      String estat = incomingDesxifrat.substring(2);

      // enviem missatge pel port sèrie
      Serial.print("r-");
      printaAddress(senderAddress);
      Serial.print("-");
      Serial.print(estat);
      Serial.println();

      // llegim la resposta
      String resposta = llegeixPortSerie();
      Serial.print("RESPOSTA: ");
      Serial.println(resposta);

      // si ha anat bé, informem al slave enviant "OK"
      if (strcmp(resposta.c_str(), "OK") == 0) {
        sendMessage(senderAddress, incomingMsgId, resposta.c_str());
        Serial.print("Sending packet: ");
        Serial.println(resposta);
      }

    }

    LoRa.receive();
    LoRa.onReceive(onReceive);
  }
  Serial.println("LoRa Receiver");
}

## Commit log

2023-10-31 primera versió encapsulat inferior
    [encapsulatInf-grupA.stl]
2023-11-07 Add temperature implementation and lora read
2023-11-10 modul gestió base de dades
2023-11-21 canvis db (#2)
    * correcció d'errors, eliminació de fitxers innecessaris, documentació i tests afegits
    * metedo fetch afegit
    * documentació del funcionament del servidor per inserir i consultar dades de la base de dades
    * modificacions en les comandes per crear les taules de la base de dades correctament
    * canvi de l'estructura de directoris
    [encapsulatInf-grupA.stl]
2023-11-23 sol·licituds POST fetes a falta de corretgir error al inserir usuaris
2023-11-23 Create Interface environment and first steps (#3)
    This commit adds web-board directory, that contains the frontend environment. Also files structure, header and footer have been added.
2023-11-28 modificació de verificaLogIn per un mètode POST encomptes de GET
2023-11-28 Canvi en l'estructura de directoris
2023-12-03 Add currentparameters components, styles fixing and minor bug fixes
2023-12-07 modificacions de totes les peticions per tal de permetre obtenir dades a partir del idUsuari en comptes del emailUsuari + correcció d'errors varis
2023-12-07 implementació funcionalitat per tenir dispositius no assignats a cap usuari, obtenir dispositius no assignats i assignar-los a un usuari + correcció d'error que permetia que un usuari tingués dos dis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
2023-12-08 implementació petició POST per modificar la contrasenya d'un usuari
2023-12-08 implementació paràmetres llindarsReg + correcció d'error que no permetia modificar cap columna de la taula dispositius
2023-12-09 afegir nomDispositiu i possibilitat s'obtenir tots els dispositius d'un usuari en la petició /obtenirUltimaDadaDispositiu
2023-12-12 Develop devices and other features
2023-12-13 primera versió de la documentació de la API en pdf
2023-12-13 funcionalitat per guardar i obtenir les modificacions en els llindars de reg de dispositius
2023-12-24 Afegida funcio obtenir ultim reg de tots els dispositius de l'usuari
2023-12-24 Afegida la documentació de la funció ultimRegUsuari de la api de la base de dades
2023-12-25 Afegida documentació de la funció desassignar dispositiu
2023-12-26 Afegir id hardcode a la taula dels dispositius i modificació de la sol·licitud d'inserir un dispositiu per afegir el id hardcode. Documentació de la funció modificada
2023-12-26 Afegit trigger per no assignar dos dispositius amb el mateix idHardcode a un usuari. Modificació funcions obtenirDispositius i obtenirDispositiusDesassignats perquè retornin idHardcode. Documentació 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
2023-12-26 Modificada funció assignaDispositiuUsuari perque retorni el idHardcode. Afegida documentació modificada de la funció
2023-12-26 Modificada funció per inserir dades d'un dispositiu perquè s'afegeixi mitjançant el idHardcode. Afegida documentació modificada de la funció
2023-12-27 Strating data pages and device add and remove interactions completed
2023-12-27 Add time filters for database information
2023-12-27 implementació dels headers d'un missatge en la comunicació master - slave
2023-12-27 inici de comunicació amb el master mitjançant interrupció del timer0
2023-12-28 Modificació base de dades perquè idHardcode sigui unic per a tothom
2023-12-28 Correcció base de dades perquè idHardcode sigui unic per a tothom. Modificació funció inserirEstatReg perquè s'hagi d'afegir amb idHardcode. Documentació modificada
2023-12-29 implementació del CRC en la comunicació LoRa entre master i slave
2024-01-03 Afegit nom del dispositiu a la resposta JSON de la petició obtenir ultim reg usuari
2024-01-04 Afegida una petició que retorna si el dispositiu està inserit a la base de dades i si està assignat a un usuari
2024-01-04 Modificació peticions modificar llindars i obtenir modificacions llindars perquè es puguin fer des del master amb el idHardcode
2024-01-05 Id hardcode shown in my devices page
2024-01-05 fitxer python per a comunicar el master (utilitzant el port sèrie) amb la API
2024-01-05 Afegides modificacions al dockerfile i a la peticio assigna dispositiu usuari de la base de dades
2024-01-07 master finalitzat a falta de la comprovació del funcionament del xifratge
2024-01-07 primera versió de la màquina d'estats del slave, funcions necessàries a implementar i mètode de repetició de missatges
2024-01-07 petita modificació per tal que el missatge només es repeteixi 5 cops
2024-01-08 Instal·lació del portal web i modificació del docker-compose perquè s'aixequi la web
2024-01-08 Afegir el servei ssh
2024-01-08 Modificació a la api de la base de dades perquè rebi sol·licituds des del domini corresponent
2024-01-08 funcionalitat per llegir dades d'humitat i de temperatura afegida
2024-01-08 implementacio total de l'estat wait_OK_bombaOFF i implementació parcial dels estats wait_OK_comprovacioReg i wait_OK_bombaON (és necessari implementar el control de la bomba correctament per a seguir)
    [slave.ino]
2024-01-08 Modificació en el docker-compose pel reinici d'un servei
2024-01-08 canvis en la màquina d'estats del slave
2024-01-08 funcionament de la màquina d'estats del slave completat + modificacions per tal de que les peticions es facin correctament
    [master.ino, master_requests.py, slave.ino]
2024-01-13 modificació dels temps de comunicació amb el master
2024-01-13 petita modificació per tal d'assegurar que la bomba no es quedi engegada sense control
2024-01-14 modificació de les peticions per https, borrat de comentaris innecessaris i limit de la humitat per evitar valors incorrectes
2024-01-14 canvis de directoris
2024-01-14 arxius 3d definitius
    [encapsulatInf-grupA.stl, encapsulatTapa-grupA.stl]
2024-01-17 Modificacio de les taules i peticions a la api per tal d'enviar un mail en registrar-se un usuari i verificar un codi
2024-01-19 Correció d'una falta en el missatge del correu
2024-01-19 Modificacio domini des d'on pot rebre peticions la api
